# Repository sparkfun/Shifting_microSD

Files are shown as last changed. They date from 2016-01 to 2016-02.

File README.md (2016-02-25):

SparkFun Shifting µSD
===================================
SparkFun Shifting µSD

[*SparkFun Shifting µSD
 (DEV-13743)*](https://www.sparkfun.com/products/13743)

 Breakout board for the microSD socket that is not much bigger than your fingernail. Compatible with the SPI interface found on any SD card, this tiny form factor was created for cell phone storage and is perfect for your next data logging project!

Repository Contents
-------------------

* **/Hardware** &mdash; All Eagle design files (.brd, .sch)
* **/Firmware** &mdash; A trivial write only Arduino word processor.
* **/Production** &mdash; Test bed files and production panel files

Documentation
--------------
* **[Hookup Guide](https://learn.sparkfun.com/tutorials/microsd-breakout-with-level-shifter-hookup-guide)** &mdash; Basic hookup guide for the Shifting µSD.
* **[SparkFun Fritzing repo](https://github.com/sparkfun/Fritzing_Parts)** &mdash; Fritzing diagrams for SparkFun products.
* **[GitHub Repository](https://github.com/sparkfun/Shifting_microSD)** &mdash; Hardware design files and source code.

Product Versions
----------------
* [DEV-13743](https://www.sparkfun.com/products/13743) &mdash; µSD socket with integrated level shifter
* [BOB-00544](https://www.sparkfun.com/products/544) &mdash; µSD socket (3.3V)

Version History
---------------
* [V_10](https://www.sparkfun.com/products/13743) &mdash; Initial release

License Information
-------------------

This product is _**open source**_!

Please review the LICENSE.md file for license information.

If you have any questions or concerns on licensing, please contact TechSupport@SparkFun.com.

Distributed as-is; no warranty is given.

&mdash; Your friends at SparkFun.

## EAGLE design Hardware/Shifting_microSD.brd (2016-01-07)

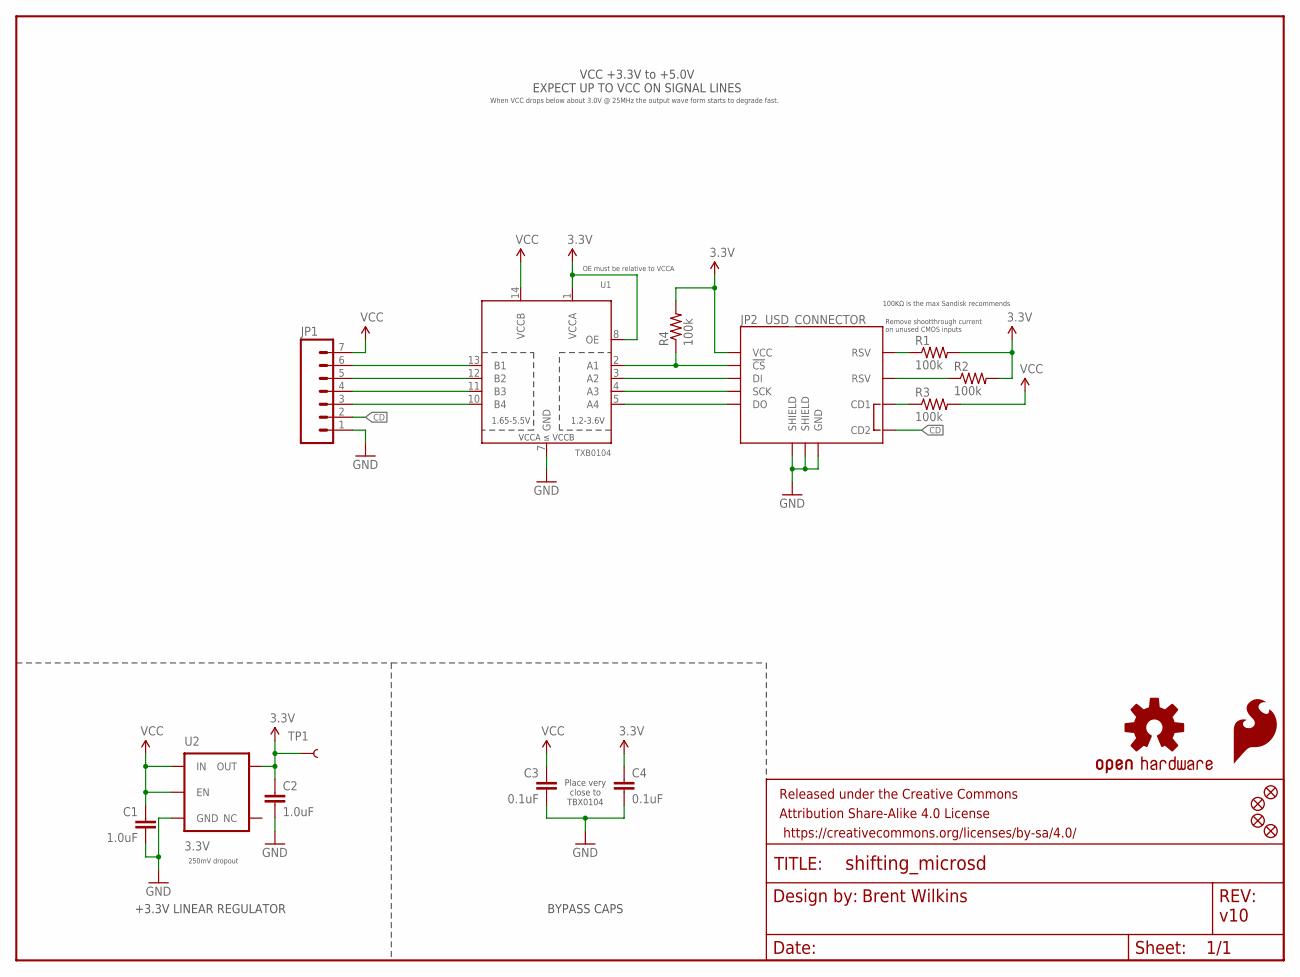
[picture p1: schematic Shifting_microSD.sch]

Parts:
C1, C2: 1.0uF; 0603-CAP
C3, C4: 0.1uF; 0603-CAP
FID1, FID2, FID3, FID4: FIDUCIAL1X2; FIDUCIAL-1X2
FRAME1: FRAME-LETTER; CREATIVE_COMMONS
JP1: M07; 1X07
JP2: USD_CONNECTOR; MICRO-SD-SOCKET-PP
LOGO1: SFE_LOGO_FLAME.2_INCH; SFE_LOGO_FLAME_.2
LOGO2: OSHW-LOGOS; OSHW-LOGO-S
R1, R2, R3, R4: 100k; 0603-RES
TP1: TEST-POINT3; PAD.03X.03
U1: TXB0104; SO14
U2: 3.3V; SOT23-5

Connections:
3V3: C2.1, C4.1, JP2.VCC, R1.2, R2.2, R4.2, TP1.P$1, U1.1 (VCCA), U1.8 (OE), U2.5 (OUT)
!CS_3V3: JP2.CS (!CS), R4.1, U1.2 (A1)
CD: JP1.2, JP2.CD2
CDSDSD: JP2.CD1, R3.1
DI: JP1.5, U1.12 (B2)
DI_3V3: JP2.DI, U1.3 (A2)
DO: JP1.3, U1.10 (B4)
DO_3V3: JP2.DO, U1.5 (A4)
GND: C1.2, C2.2, C3.2, C4.2, JP1.1, JP2.GND, JP2.GND1 (SHIELD), JP2.GND3 (SHIELD), U1.7 (GND), U2.2 (GND)
unnamed: JP1.6, U1.13 (B1)
unnamed: JP1.4, U1.11 (B3)
RSV@1: JP2.RSV1 (RSV), R1.1
RSV@2: JP2.RSV2 (RSV), R2.1
SCK_3V3: JP2.SCLK (SCK), U1.4 (A3)
VDD_IO: C1.1, C3.1, JP1.7, R3.2, U1.14 (VCCB), U2.1 (IN), U2.3 (EN)

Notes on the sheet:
Brent Wilkins
v10
VCC +3.3V to +5.0V EXPECT UP TO VCC ON SIGNAL LINES
Remove shootthrough current on unused CMOS inputs
Place very close to TBX0104
OE must be relative to VCCA
When VCC drops below about 3.0V @ 25MHz the output wave form starts to degrade fast.
+3.3V LINEAR REGULATOR
BYPASS CAPS
100KΩ is the max Sandisk recommends
250mV dropout

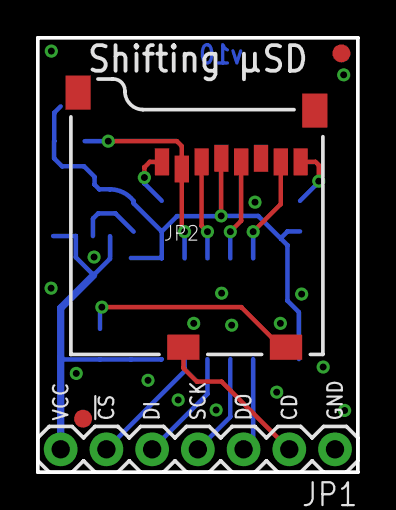
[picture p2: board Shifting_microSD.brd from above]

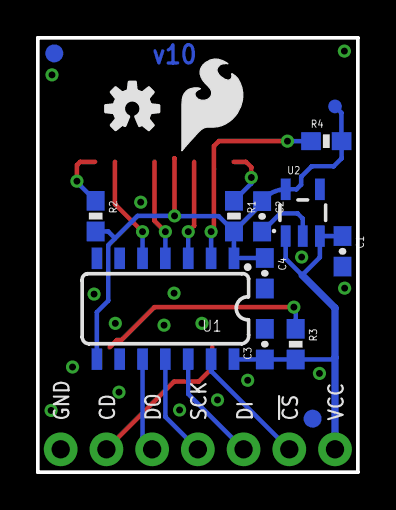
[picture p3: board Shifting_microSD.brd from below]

Board: 2 copper layers, 17.8 x 24.1 mm, 20 parts (15 on the bottom side), 15 nets.

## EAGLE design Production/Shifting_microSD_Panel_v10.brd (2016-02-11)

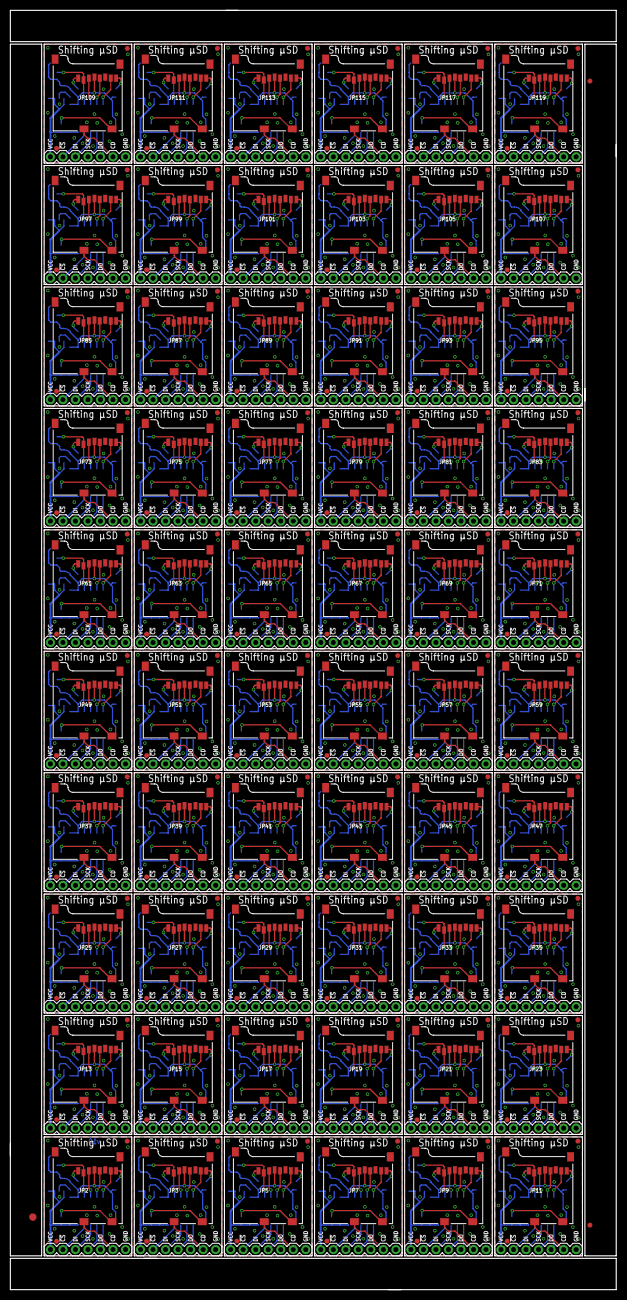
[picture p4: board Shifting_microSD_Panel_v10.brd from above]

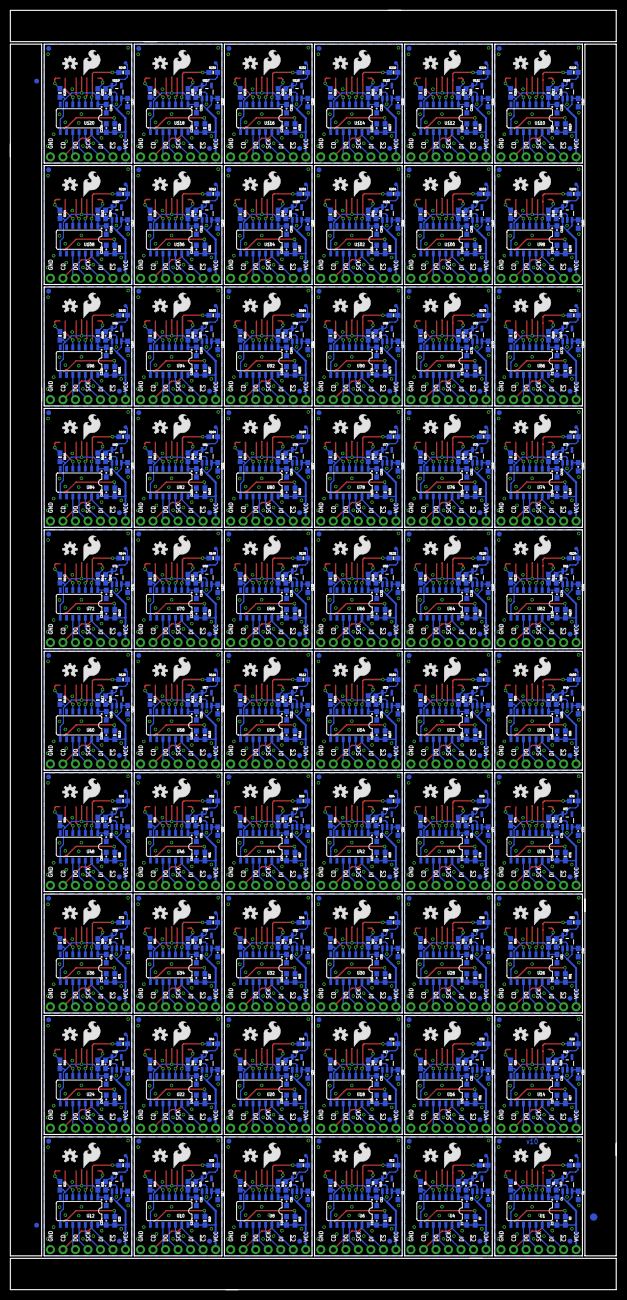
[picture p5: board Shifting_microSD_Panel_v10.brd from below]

Board: 2 copper layers, 122.9 x 259.6 mm, 1146 parts (903 on the bottom side), 900 nets.

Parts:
C1, C2, C5, C6, C9, C10, C13, C14, C17, C18, C21, C22, C25, C26, C29, C30, C33, C34, C37, C38, C41, C42, C45, C46, C49, C50, C53, C54, C57, C58, C61, C62, C65, C66, C69, C70, C73, C74, C77, C78, C81, C82, C85, C86, C89, C90, C93, C94, C97, C98, C101, C102, C105, C106, C109, C110, C113, C114, C117, C118, C121, C122, C125, C126, C129, C130, C133, C134, C137, C138, C141, C142, C145, C146, C149, C150, C153, C154, C157, C158, C161, C162, C165, C166, C169, C170, C173, C174, C177, C178, C181, C182, C185, C186, C189, C190, C193, C194, C197, C198, C201, C202, C205, C206, C209, C210, C213, C214, C217, C218, C221, C222, C225, C226, C229, C230, C233, C234, C237, C238: 1.0uF; 0603-CAP
C3, C4, C7, C8, C11, C12, C15, C16, C19, C20, C23, C24, C27, C28, C31, C32, C35, C36, C39, C40, C43, C44, C47, C48, C51, C52, C55, C56, C59, C60, C63, C64, C67, C68, C71, C72, C75, C76, C79, C80, C83, C84, C87, C88, C91, C92, C95, C96, C99, C100, C103, C104, C107, C108, C111, C112, C115, C116, C119, C120, C123, C124, C127, C128, C131, C132, C135, C136, C139, C140, C143, C144, C147, C148, C151, C152, C155, C156, C159, C160, C163, C164, C167, C168, C171, C172, C175, C176, C179, C180, C183, C184, C187, C188, C191, C192, C195, C196, C199, C200, C203, C204, C207, C208, C211, C212, C215, C216, C219, C220, C223, C224, C227, C228, C231, C232, C235, C236, C239, C240: 0.1uF; 0603-CAP
E$1, E$4, E$5, E$6: FIDUCIAL-1X2
E$2, E$3: FIDUCIAL-1.5X3
FID1, FID2, FID3, FID4, FID5, FID6, FID7, FID8, FID9, FID10, FID11, FID12, FID13, FID14, FID15, FID16, FID17, FID18, FID19, FID20, FID21, FID22, FID23, FID24, FID25, FID26, FID27, FID28, FID29, FID30, FID31, FID32, FID33, FID34, FID35, FID36, FID37, FID38, FID39, FID40, FID41, FID42, FID43, FID44, FID45, FID46, FID47, FID48, FID49, FID50, FID51, FID52, FID53, FID54, FID55, FID56, FID57, FID58, FID59, FID60, FID61, FID62, FID63, FID64, FID65, FID66, FID67, FID68, FID69, FID70, FID71, FID72, FID73, FID74, FID75, FID76, FID77, FID78, FID79, FID80, FID81, FID82, FID83, FID84, FID85, FID86, FID87, FID88, FID89, FID90, FID91, FID92, FID93, FID94, FID95, FID96, FID97, FID98, FID99, FID100, FID101, FID102, FID103, FID104, FID105, FID106, FID107, FID108, FID109, FID110, FID111, FID112, FID113, FID114, FID115, FID116, FID117, FID118, FID119, FID120, FID121, FID122, FID123, FID124, FID125, FID126, FID127, FID128, FID129, FID130, FID131, FID132, FID133, FID134, FID135, FID136, FID137, FID138, FID139, FID140, FID141, FID142, FID143, FID144, FID145, FID146, FID147, FID148, FID149, FID150, FID151, FID152, FID153, FID154, FID155, FID156, FID157, FID158, FID159, FID160, FID161, FID162, FID163, FID164, FID165, FID166, FID167, FID168, FID169, FID170, FID171, FID172, FID173, FID174, FID175, FID176, FID177, FID178, FID179, FID180, FID181, FID182, FID183, FID184, FID185, FID186, FID187, FID188, FID189, FID190, FID191, FID192, FID193, FID194, FID195, FID196, FID197, FID198, FID199, FID200, FID201, FID202, FID203, FID204, FID205, FID206, FID207, FID208, FID209, FID210, FID211, FID212, FID213, FID214, FID215, FID216, FID217, FID218, FID219, FID220, FID221, FID222, FID223, FID224, FID225, FID226, FID227, FID228, FID229, FID230, FID231, FID232, FID233, FID234, FID235, FID236, FID237, FID238, FID239, FID240: FIDUCIAL1X2; FIDUCIAL-1X2
JP1, JP4, JP6, JP8, JP10, JP12, JP14, JP16, JP18, JP20, JP22, JP24, JP26, JP28, JP30, JP32, JP34, JP36, JP38, JP40, JP42, JP44, JP46, JP48, JP50, JP52, JP54, JP56, JP58, JP60, JP62, JP64, JP66, JP68, JP70, JP72, JP74, JP76, JP78, JP80, JP82, JP84, JP86, JP88, JP90, JP92, JP94, JP96, JP98, JP100, JP102, JP104, JP106, JP108, JP110, JP112, JP114, JP116, JP118, JP120: 1X07
JP2, JP3, JP5, JP7, JP9, JP11, JP13, JP15, JP17, JP19, JP21, JP23, JP25, JP27, JP29, JP31, JP33, JP35, JP37, JP39, JP41, JP43, JP45, JP47, JP49, JP51, JP53, JP55, JP57, JP59, JP61, JP63, JP65, JP67, JP69, JP71, JP73, JP75, JP77, JP79, JP81, JP83, JP85, JP87, JP89, JP91, JP93, JP95, JP97, JP99, JP101, JP103, JP105, JP107, JP109, JP111, JP113, JP115, JP117, JP119: USD_CONNECTOR; MICRO-SD-SOCKET-PP
LOGO1, LOGO3, LOGO5, LOGO7, LOGO9, LOGO11, LOGO13, LOGO15, LOGO17, LOGO19, LOGO21, LOGO23, LOGO25, LOGO27, LOGO29, LOGO31, LOGO33, LOGO35, LOGO37, LOGO39, LOGO41, LOGO43, LOGO45, LOGO47, LOGO49, LOGO51, LOGO53, LOGO55, LOGO57, LOGO59, LOGO61, LOGO63, LOGO65, LOGO67, LOGO69, LOGO71, LOGO73, LOGO75, LOGO77, LOGO79, LOGO81, LOGO83, LOGO85, LOGO87, LOGO89, LOGO91, LOGO93, LOGO95, LOGO97, LOGO99, LOGO101, LOGO103, LOGO105, LOGO107, LOGO109, LOGO111, LOGO113, LOGO115, LOGO117, LOGO119: SFE_LOGO_FLAME.2_INCH; SFE_LOGO_FLAME_.2
LOGO2, LOGO4, LOGO6, LOGO8, LOGO10, LOGO12, LOGO14, LOGO16, LOGO18, LOGO20, LOGO22, LOGO24, LOGO26, LOGO28, LOGO30, LOGO32, LOGO34, LOGO36, LOGO38, LOGO40, LOGO42, LOGO44, LOGO46, LOGO48, LOGO50, LOGO52, LOGO54, LOGO56, LOGO58, LOGO60, LOGO62, LOGO64, LOGO66, LOGO68, LOGO70, LOGO72, LOGO74, LOGO76, LOGO78, LOGO80, LOGO82, LOGO84, LOGO86, LOGO88, LOGO90, LOGO92, LOGO94, LOGO96, LOGO98, LOGO100, LOGO102, LOGO104, LOGO106, LOGO108, LOGO110, LOGO112, LOGO114, LOGO116, LOGO118, LOGO120: OSHW-LOGOS; OSHW-LOGO-S
R1, R2, R3, R4, R5, R6, R7, R8, R9, R10, R11, R12, R13, R14, R15, R16, R17, R18, R19, R20, R21, R22, R23, R24, R25, R26, R27, R28, R29, R30, R31, R32, R33, R34, R35, R36, R37, R38, R39, R40, R41, R42, R43, R44, R45, R46, R47, R48, R49, R50, R51, R52, R53, R54, R55, R56, R57, R58, R59, R60, R61, R62, R63, R64, R65, R66, R67, R68, R69, R70, R71, R72, R73, R74, R75, R76, R77, R78, R79, R80, R81, R82, R83, R84, R85, R86, R87, R88, R89, R90, R91, R92, R93, R94, R95, R96, R97, R98, R99, R100, R101, R102, R103, R104, R105, R106, R107, R108, R109, R110, R111, R112, R113, R114, R115, R116, R117, R118, R119, R120, R121, R122, R123, R124, R125, R126, R127, R128, R129, R130, R131, R132, R133, R134, R135, R136, R137, R138, R139, R140, R141, R142, R143, R144, R145, R146, R147, R148, R149, R150, R151, R152, R153, R154, R155, R156, R157, R158, R159, R160, R161, R162, R163, R164, R165, R166, R167, R168, R169, R170, R171, R172, R173, R174, R175, R176, R177, R178, R179, R180, R181, R182, R183, R184, R185, R186, R187, R188, R189, R190, R191, R192, R193, R194, R195, R196, R197, R198, R199, R200, R201, R202, R203, R204, R205, R206, R207, R208, R209, R210, R211, R212, R213, R214, R215, R216, R217, R218, R219, R220, R221, R222, R223, R224, R225, R226, R227, R228, R229, R230, R231, R232, R233, R234, R235, R236, R237, R238, R239, R240: 100k; 0603-RES
TP1, TP2, TP3, TP4, TP5, TP6, TP7, TP8, TP9, TP10, TP11, TP12, TP13, TP14, TP15, TP16, TP17, TP18, TP19, TP20, TP21, TP22, TP23, TP24, TP25, TP26, TP27, TP28, TP29, TP30, TP31, TP32, TP33, TP34, TP35, TP36, TP37, TP38, TP39, TP40, TP41, TP42, TP43, TP44, TP45, TP46, TP47, TP48, TP49, TP50, TP51, TP52, TP53, TP54, TP55, TP56, TP57, TP58, TP59, TP60: PAD.03X.03
U1, U4, U6, U8, U10, U12, U14, U16, U18, U20, U22, U24, U26, U28, U30, U32, U34, U36, U38, U40, U42, U44, U46, U48, U50, U52, U54, U56, U58, U60, U62, U64, U66, U68, U70, U72, U74, U76, U78, U80, U82, U84, U86, U88, U90, U92, U94, U96, U98, U100, U102, U104, U106, U108, U110, U112, U114, U116, U118, U120: TXB0104; SO14
U2, U3, U5, U7, U9, U11, U13, U15, U17, U19, U21, U23, U25, U27, U29, U31, U33, U35, U37, U39, U41, U43, U45, U47, U49, U51, U53, U55, U57, U59, U61, U63, U65, U67, U69, U71, U73, U75, U77, U79, U81, U83, U85, U87, U89, U91, U93, U95, U97, U99, U101, U103, U105, U107, U109, U111, U113, U115, U117, U119: 3.3V; SOT23-5

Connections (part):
3V1: C6.1, C8.1, JP3.VCC, R5.2, R6.2, R8.2, TP2.P$1, U3.5, U4.1, U4.8
3V2: C10.1, C12.1, JP5.VCC, R9.2, R10.2, R12.2, TP3.P$1, U5.5, U6.1, U6.8
3V3: C2.1, C4.1, JP2.VCC, R1.2, R2.2, R4.2, TP1.P$1, U1.1, U1.8, U2.5
3V4: C14.1, C16.1, JP7.VCC, R13.2, R14.2, R16.2, TP4.P$1, U7.5, U8.1, U8.8
3V5: C18.1, C20.1, JP9.VCC, R17.2, R18.2, R20.2, TP5.P$1, U9.5, U10.1, U10.8
3V6: C22.1, C24.1, JP11.VCC, R21.2, R22.2, R24.2, TP6.P$1, U11.5, U12.1, U12.8
3V7: C26.1, C28.1, JP13.VCC, R25.2, R26.2, R28.2, TP7.P$1, U13.5, U14.1, U14.8
3V8: C30.1, C32.1, JP15.VCC, R29.2, R30.2, R32.2, TP8.P$1, U15.5, U16.1, U16.8
3V9: C34.1, C36.1, JP17.VCC, R33.2, R34.2, R36.2, TP9.P$1, U17.5, U18.1, U18.8
3V10: C38.1, C40.1, JP19.VCC, R37.2, R38.2, R40.2, TP10.P$1, U19.5, U20.1, U20.8
3V11: C42.1, C44.1, JP21.VCC, R41.2, R42.2, R44.2, TP11.P$1, U21.5, U22.1, U22.8
3V12: C46.1, C48.1, JP23.VCC, R45.2, R46.2, R48.2, TP12.P$1, U23.5, U24.1, U24.8
3V13: C50.1, C52.1, JP25.VCC, R49.2, R50.2, R52.2, TP13.P$1, U25.5, U26.1, U26.8
3V14: C54.1, C56.1, JP27.VCC, R53.2, R54.2, R56.2, TP14.P$1, U27.5, U28.1, U28.8
3V15: C58.1, C60.1, JP29.VCC, R57.2, R58.2, R60.2, TP15.P$1, U29.5, U30.1, U30.8
3V16: C62.1, C64.1, JP31.VCC, R61.2, R62.2, R64.2, TP16.P$1, U31.5, U32.1, U32.8
3V17: C66.1, C68.1, JP33.VCC, R65.2, R66.2, R68.2, TP17.P$1, U33.5, U34.1, U34.8
3V18: C70.1, C72.1, JP35.VCC, R69.2, R70.2, R72.2, TP18.P$1, U35.5, U36.1, U36.8
3V19: C74.1, C76.1, JP37.VCC, R73.2, R74.2, R76.2, TP19.P$1, U37.5, U38.1, U38.8
3V20: C78.1, C80.1, JP39.VCC, R77.2, R78.2, R80.2, TP20.P$1, U39.5, U40.1, U40.8
3V21: C82.1, C84.1, JP41.VCC, R81.2, R82.2, R84.2, TP21.P$1, U41.5, U42.1, U42.8
3V22: C86.1, C88.1, JP43.VCC, R85.2, R86.2, R88.2, TP22.P$1, U43.5, U44.1, U44.8
3V23: C90.1, C92.1, JP45.VCC, R89.2, R90.2, R92.2, TP23.P$1, U45.5, U46.1, U46.8
3V24: C94.1, C96.1, JP47.VCC, R93.2, R94.2, R96.2, TP24.P$1, U47.5, U48.1, U48.8
3V25: C98.1, C100.1, JP49.VCC, R97.2, R98.2, R100.2, TP25.P$1, U49.5, U50.1, U50.8
3V26: C102.1, C104.1, JP51.VCC, R101.2, R102.2, R104.2, TP26.P$1, U51.5, U52.1, U52.8
3V27: C106.1, C108.1, JP53.VCC, R105.2, R106.2, R108.2, TP27.P$1, U53.5, U54.1, U54.8
3V28: C110.1, C112.1, JP55.VCC, R109.2, R110.2, R112.2, TP28.P$1, U55.5, U56.1, U56.8
3V29: C114.1, C116.1, JP57.VCC, R113.2, R114.2, R116.2, TP29.P$1, U57.5, U58.1, U58.8
3V30: C118.1, C120.1, JP59.VCC, R117.2, R118.2, R120.2, TP30.P$1, U59.5, U60.1, U60.8
3V31: C122.1, C124.1, JP61.VCC, R121.2, R122.2, R124.2, TP31.P$1, U61.5, U62.1, U62.8
3V32: C126.1, C128.1, JP63.VCC, R125.2, R126.2, R128.2, TP32.P$1, U63.5, U64.1, U64.8
3V33: C130.1, C132.1, JP65.VCC, R129.2, R130.2, R132.2, TP33.P$1, U65.5, U66.1, U66.8
3V34: C134.1, C136.1, JP67.VCC, R133.2, R134.2, R136.2, TP34.P$1, U67.5, U68.1, U68.8
3V35: C138.1, C140.1, JP69.VCC, R137.2, R138.2, R140.2, TP35.P$1, U69.5, U70.1, U70.8
3V36: C142.1, C144.1, JP71.VCC, R141.2, R142.2, R144.2, TP36.P$1, U71.5, U72.1, U72.8
3V37: C146.1, C148.1, JP73.VCC, R145.2, R146.2, R148.2, TP37.P$1, U73.5, U74.1, U74.8
3V38: C150.1, C152.1, JP75.VCC, R149.2, R150.2, R152.2, TP38.P$1, U75.5, U76.1, U76.8
3V39: C154.1, C156.1, JP77.VCC, R153.2, R154.2, R156.2, TP39.P$1, U77.5, U78.1, U78.8
3V40: C158.1, C160.1, JP79.VCC, R157.2, R158.2, R160.2, TP40.P$1, U79.5, U80.1, U80.8
3V41: C162.1, C164.1, JP81.VCC, R161.2, R162.2, R164.2, TP41.P$1, U81.5, U82.1, U82.8
3V42: C166.1, C168.1, JP83.VCC, R165.2, R166.2, R168.2, TP42.P$1, U83.5, U84.1, U84.8
3V43: C170.1, C172.1, JP85.VCC, R169.2, R170.2, R172.2, TP43.P$1, U85.5, U86.1, U86.8
3V44: C174.1, C176.1, JP87.VCC, R173.2, R174.2, R176.2, TP44.P$1, U87.5, U88.1, U88.8
3V45: C178.1, C180.1, JP89.VCC, R177.2, R178.2, R180.2, TP45.P$1, U89.5, U90.1, U90.8
3V46: C182.1, C184.1, JP91.VCC, R181.2, R182.2, R184.2, TP46.P$1, U91.5, U92.1, U92.8
3V47: C186.1, C188.1, JP93.VCC, R185.2, R186.2, R188.2, TP47.P$1, U93.5, U94.1, U94.8
3V48: C190.1, C192.1, JP95.VCC, R189.2, R190.2, R192.2, TP48.P$1, U95.5, U96.1, U96.8
3V49: C194.1, C196.1, JP97.VCC, R193.2, R194.2, R196.2, TP49.P$1, U97.5, U98.1, U98.8
3V50: C198.1, C200.1, JP99.VCC, R197.2, R198.2, R200.2, TP50.P$1, U99.5, U100.1, U100.8
3V51: C202.1, C204.1, JP101.VCC, R201.2, R202.2, R204.2, TP51.P$1, U101.5, U102.1, U102.8
3V52: C206.1, C208.1, JP103.VCC, R205.2, R206.2, R208.2, TP52.P$1, U103.5, U104.1, U104.8
3V53: C210.1, C212.1, JP105.VCC, R209.2, R210.2, R212.2, TP53.P$1, U105.5, U106.1, U106.8
3V54: C214.1, C216.1, JP107.VCC, R213.2, R214.2, R216.2, TP54.P$1, U107.5, U108.1, U108.8
3V55: C218.1, C220.1, JP109.VCC, R217.2, R218.2, R220.2, TP55.P$1, U109.5, U110.1, U110.8
3V56: C222.1, C224.1, JP111.VCC, R221.2, R222.2, R224.2, TP56.P$1, U111.5, U112.1, U112.8
3V57: C226.1, C228.1, JP113.VCC, R225.2, R226.2, R228.2, TP57.P$1, U113.5, U114.1, U114.8
3V58: C230.1, C232.1, JP115.VCC, R229.2, R230.2, R232.2, TP58.P$1, U115.5, U116.1, U116.8
3V59: C234.1, C236.1, JP117.VCC, R233.2, R234.2, R236.2, TP59.P$1, U117.5, U118.1, U118.8
3V60: C238.1, C240.1, JP119.VCC, R237.2, R238.2, R240.2, TP60.P$1, U119.5, U120.1, U120.8
!CS_3V1: JP3.CS, R8.1, U4.2
!CS_3V2: JP5.CS, R12.1, U6.2
!CS_3V3: JP2.CS, R4.1, U1.2
!CS_3V4: JP7.CS, R16.1, U8.2
!CS_3V5: JP9.CS, R20.1, U10.2
!CS_3V6: JP11.CS, R24.1, U12.2
!CS_3V7: JP13.CS, R28.1, U14.2
!CS_3V8: JP15.CS, R32.1, U16.2
!CS_3V9: JP17.CS, R36.1, U18.2
!CS_3V10: JP19.CS, R40.1, U20.2
!CS_3V11: JP21.CS, R44.1, U22.2
!CS_3V12: JP23.CS, R48.1, U24.2
!CS_3V13: JP25.CS, R52.1, U26.2
!CS_3V14: JP27.CS, R56.1, U28.2
!CS_3V15: JP29.CS, R60.1, U30.2
!CS_3V16: JP31.CS, R64.1, U32.2
!CS_3V17: JP33.CS, R68.1, U34.2
!CS_3V18: JP35.CS, R72.1, U36.2
!CS_3V19: JP37.CS, R76.1, U38.2
!CS_3V20: JP39.CS, R80.1, U40.2
!CS_3V21: JP41.CS, R84.1, U42.2
!CS_3V22: JP43.CS, R88.1, U44.2
!CS_3V23: JP45.CS, R92.1, U46.2
!CS_3V24: JP47.CS, R96.1, U48.2
!CS_3V25: JP49.CS, R100.1, U50.2
!CS_3V26: JP51.CS, R104.1, U52.2
!CS_3V27: JP53.CS, R108.1, U54.2
!CS_3V28: JP55.CS, R112.1, U56.2
!CS_3V29: JP57.CS, R116.1, U58.2
!CS_3V30: JP59.CS, R120.1, U60.2
!CS_3V31: JP61.CS, R124.1, U62.2
!CS_3V32: JP63.CS, R128.1, U64.2
!CS_3V33: JP65.CS, R132.1, U66.2
!CS_3V34: JP67.CS, R136.1, U68.2
!CS_3V35: JP69.CS, R140.1, U70.2
!CS_3V36: JP71.CS, R144.1, U72.2
!CS_3V37: JP73.CS, R148.1, U74.2
!CS_3V38: JP75.CS, R152.1, U76.2
!CS_3V39: JP77.CS, R156.1, U78.2
!CS_3V40: JP79.CS, R160.1, U80.2
!CS_3V41: JP81.CS, R164.1, U82.2
!CS_3V42: JP83.CS, R168.1, U84.2
!CS_3V43: JP85.CS, R172.1, U86.2
!CS_3V44: JP87.CS, R176.1, U88.2
!CS_3V45: JP89.CS, R180.1, U90.2
!CS_3V46: JP91.CS, R184.1, U92.2
!CS_3V47: JP93.CS, R188.1, U94.2
!CS_3V48: JP95.CS, R192.1, U96.2
!CS_3V49: JP97.CS, R196.1, U98.2
!CS_3V50: JP99.CS, R200.1, U100.2
!CS_3V51: JP101.CS, R204.1, U102.2
!CS_3V52: JP103.CS, R208.1, U104.2
!CS_3V53: JP105.CS, R212.1, U106.2
!CS_3V54: JP107.CS, R216.1, U108.2
!CS_3V55: JP109.CS, R220.1, U110.2
!CS_3V56: JP111.CS, R224.1, U112.2
!CS_3V57: JP113.CS, R228.1, U114.2
!CS_3V58: JP115.CS, R232.1, U116.2
!CS_3V59: JP117.CS, R236.1, U118.2
!CS_3V60: JP119.CS, R240.1, U120.2
CD: JP1.2, JP2.CD2
CD1: JP3.CD2, JP4.2
CD2: JP5.CD2, JP6.2
CD3: JP7.CD2, JP8.2
CD4: JP9.CD2, JP10.2
CD5: JP11.CD2, JP12.2
CD6: JP13.CD2, JP14.2
CD7: JP15.CD2, JP16.2
CD8: JP17.CD2, JP18.2
CD9: JP19.CD2, JP20.2
CD10: JP21.CD2, JP22.2
CD11: JP23.CD2, JP24.2
CD12: JP25.CD2, JP26.2
CD13: JP27.CD2, JP28.2
CD14: JP29.CD2, JP30.2
CD15: JP31.CD2, JP32.2
CD16: JP33.CD2, JP34.2
CD17: JP35.CD2, JP36.2
CD18: JP37.CD2, JP38.2
CD19: JP39.CD2, JP40.2
CD20: JP41.CD2, JP42.2
CD21: JP43.CD2, JP44.2
CD22: JP45.CD2, JP46.2
CD23: JP47.CD2, JP48.2
CD24: JP49.CD2, JP50.2
CD25: JP51.CD2, JP52.2
CD26: JP53.CD2, JP54.2
CD27: JP55.CD2, JP56.2
CD28: JP57.CD2, JP58.2
CD29: JP59.CD2, JP60.2
CD30: JP61.CD2, JP62.2
CD31: JP63.CD2, JP64.2
CD32: JP65.CD2, JP66.2
CD33: JP67.CD2, JP68.2
CD34: JP69.CD2, JP70.2
CD35: JP71.CD2, JP72.2
CD36: JP73.CD2, JP74.2
CD37: JP75.CD2, JP76.2
CD38: JP77.CD2, JP78.2
CD39: JP79.CD2, JP80.2
CD40: JP81.CD2, JP82.2
CD41: JP83.CD2, JP84.2
CD42: JP85.CD2, JP86.2
CD43: JP87.CD2, JP88.2
CD44: JP89.CD2, JP90.2
CD45: JP91.CD2, JP92.2
CD46: JP93.CD2, JP94.2
CD47: JP95.CD2, JP96.2
CD48: JP97.CD2, JP98.2
CD49: JP99.CD2, JP100.2
CD50: JP101.CD2, JP102.2
CD51: JP103.CD2, JP104.2
CD52: JP105.CD2, JP106.2
CD53: JP107.CD2, JP108.2
CD54: JP109.CD2, JP110.2
CD55: JP111.CD2, JP112.2
CD56: JP113.CD2, JP114.2
CD57: JP115.CD2, JP116.2
CD58: JP117.CD2, JP118.2
CD59: JP119.CD2, JP120.2
CDSDSD: JP2.CD1, R3.1
CDSDSD1: JP3.CD1, R7.1
CDSDSD2: JP5.CD1, R11.1
CDSDSD3: JP7.CD1, R15.1
CDSDSD4: JP9.CD1, R19.1
CDSDSD5: JP11.CD1, R23.1
CDSDSD6: JP13.CD1, R27.1
CDSDSD7: JP15.CD1, R31.1
CDSDSD8: JP17.CD1, R35.1
CDSDSD9: JP19.CD1, R39.1
CDSDSD10: JP21.CD1, R43.1
CDSDSD11: JP23.CD1, R47.1
CDSDSD12: JP25.CD1, R51.1
CDSDSD13: JP27.CD1, R55.1
CDSDSD14: JP29.CD1, R59.1
CDSDSD15: JP31.CD1, R63.1
CDSDSD16: JP33.CD1, R67.1
CDSDSD17: JP35.CD1, R71.1
CDSDSD18: JP37.CD1, R75.1
CDSDSD19: JP39.CD1, R79.1
CDSDSD20: JP41.CD1, R83.1
CDSDSD21: JP43.CD1, R87.1
CDSDSD22: JP45.CD1, R91.1
CDSDSD23: JP47.CD1, R95.1
CDSDSD24: JP49.CD1, R99.1
CDSDSD25: JP51.CD1, R103.1
CDSDSD26: JP53.CD1, R107.1
CDSDSD27: JP55.CD1, R111.1
CDSDSD28: JP57.CD1, R115.1
CDSDSD29: JP59.CD1, R119.1
CDSDSD30: JP61.CD1, R123.1
CDSDSD31: JP63.CD1, R127.1
CDSDSD32: JP65.CD1, R131.1
CDSDSD33: JP67.CD1, R135.1
CDSDSD34: JP69.CD1, R139.1
CDSDSD35: JP71.CD1, R143.1
CDSDSD36: JP73.CD1, R147.1
CDSDSD37: JP75.CD1, R151.1
CDSDSD38: JP77.CD1, R155.1
CDSDSD39: JP79.CD1, R159.1
CDSDSD40: JP81.CD1, R163.1
CDSDSD41: JP83.CD1, R167.1
CDSDSD42: JP85.CD1, R171.1
CDSDSD43: JP87.CD1, R175.1
CDSDSD44: JP89.CD1, R179.1
CDSDSD45: JP91.CD1, R183.1
CDSDSD46: JP93.CD1, R187.1
CDSDSD47: JP95.CD1, R191.1
CDSDSD48: JP97.CD1, R195.1
CDSDSD49: JP99.CD1, R199.1
CDSDSD50: JP101.CD1, R203.1
CDSDSD51: JP103.CD1, R207.1
CDSDSD52: JP105.CD1, R211.1
CDSDSD53: JP107.CD1, R215.1
CDSDSD54: JP109.CD1, R219.1
CDSDSD55: JP111.CD1, R223.1
CDSDSD56: JP113.CD1, R227.1
CDSDSD57: JP115.CD1, R231.1
CDSDSD58: JP117.CD1, R235.1
CDSDSD59: JP119.CD1, R239.1
DI: JP1.5, U1.12
DI1: JP4.5, U4.12
DI2: JP6.5, U6.12
DI3: JP8.5, U8.12
DI4: JP10.5, U10.12
DI5: JP12.5, U12.12
DI6: JP14.5, U14.12
DI7: JP16.5, U16.12
DI8: JP18.5, U18.12
DI9: JP20.5, U20.12
DI10: JP22.5, U22.12
DI11: JP24.5, U24.12
DI12: JP26.5, U26.12
DI13: JP28.5, U28.12
DI14: JP30.5, U30.12
DI15: JP32.5, U32.12
DI16: JP34.5, U34.12
DI17: JP36.5, U36.12
DI18: JP38.5, U38.12
DI19: JP40.5, U40.12
DI20: JP42.5, U42.12
DI21: JP44.5, U44.12
DI22: JP46.5, U46.12
DI23: JP48.5, U48.12
DI24: JP50.5, U50.12
DI25: JP52.5, U52.12
DI26: JP54.5, U54.12
DI27: JP56.5, U56.12
DI28: JP58.5, U58.12
DI29: JP60.5, U60.12
DI30: JP62.5, U62.12
DI31: JP64.5, U64.12
DI32: JP66.5, U66.12
DI33: JP68.5, U68.12
DI34: JP70.5, U70.12
DI35: JP72.5, U72.12
DI36: JP74.5, U74.12
DI37: JP76.5, U76.12
DI38: JP78.5, U78.12
DI39: JP80.5, U80.12
DI40: JP82.5, U82.12
DI41: JP84.5, U84.12
DI42: JP86.5, U86.12
DI43: JP88.5, U88.12
DI44: JP90.5, U90.12
DI45: JP92.5, U92.12
DI46: JP94.5, U94.12
DI47: JP96.5, U96.12
DI48: JP98.5, U98.12
DI49: JP100.5, U100.12
DI50: JP102.5, U102.12
DI51: JP104.5, U104.12
DI52: JP106.5, U106.12
DI53: JP108.5, U108.12
DI54: JP110.5, U110.12
DI55: JP112.5, U112.12
DI56: JP114.5, U114.12
DI57: JP116.5, U116.12
DI58: JP118.5, U118.12
DI59: JP120.5, U120.12
DI_3V1: JP3.DI, U4.3
DI_3V2: JP5.DI, U6.3
DI_3V3: JP2.DI, U1.3
DI_3V4: JP7.DI, U8.3
DI_3V5: JP9.DI, U10.3
DI_3V6: JP11.DI, U12.3
DI_3V7: JP13.DI, U14.3
DI_3V8: JP15.DI, U16.3
DI_3V9: JP17.DI, U18.3
DI_3V10: JP19.DI, U20.3
DI_3V11: JP21.DI, U22.3
DI_3V12: JP23.DI, U24.3
DI_3V13: JP25.DI, U26.3
DI_3V14: JP27.DI, U28.3
DI_3V15: JP29.DI, U30.3
DI_3V16: JP31.DI, U32.3
DI_3V17: JP33.DI, U34.3
DI_3V18: JP35.DI, U36.3
DI_3V19: JP37.DI, U38.3
DI_3V20: JP39.DI, U40.3
DI_3V21: JP41.DI, U42.3
DI_3V22: JP43.DI, U44.3
DI_3V23: JP45.DI, U46.3
DI_3V24: JP47.DI, U48.3
DI_3V25: JP49.DI, U50.3
DI_3V26: JP51.DI, U52.3
DI_3V27: JP53.DI, U54.3
DI_3V28: JP55.DI, U56.3
DI_3V29: JP57.DI, U58.3
DI_3V30: JP59.DI, U60.3
DI_3V31: JP61.DI, U62.3
DI_3V32: JP63.DI, U64.3
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

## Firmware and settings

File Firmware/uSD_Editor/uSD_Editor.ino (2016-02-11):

/*
 * A simple file logger that allows the user to write to a file on the µSD card
 * using the Arduino IDE Serial Monitor (57600 baud). Entered text is written
 * to the µSD card every 20 characters, but to make sure everything is written
 * append 'EOF' to your writing. Doing so writes everything remaining in the
 * buffer to the file and reads back the contents of the file.
 */

#include <SPI.h>
#include <SD.h>

File fd;
const uint8_t BUFFER_SIZE = 20;
char fileName[] = "demoFile.txt"; // SD library only supports up to 8.3 names
char buff[BUFFER_SIZE+2] = "";  // Added two to allow a 2 char peek for EOF state
uint8_t index = 0;

const uint8_t chipSelect = 8;
const uint8_t cardDetect = 9;

enum states: uint8_t { NORMAL, E, EO };
uint8_t state = NORMAL;

bool alreadyBegan = false;  // SD.begin() misbehaves if not first call



////////////////////////////////////////////////////////////////////////////////
// Standard Arduino setup function
////////////////////////////////////////////////////////////////////////////////
void setup()
{
  Serial.begin(57600);
  while (!Serial);  // Wait for serial port to connect (ATmega32U4 type PCBAs)

  // Note: To satisfy the AVR SPI gods the SD library takes care of setting
  // SS_PIN as an output. We don't need to.
  pinMode(cardDetect, INPUT);

  initializeCard();
}



////////////////////////////////////////////////////////////////////////////////
// Arduino calls this function over and over again when running
////////////////////////////////////////////////////////////////////////////////
void loop()
{
  // Make sure the card is still present
  if (!digitalRead(cardDetect))
  {
    initializeCard();
  }

  if (Serial.available() > 0)
  {
    readByte();
    
    if (index == BUFFER_SIZE)
    {
      flushBuffer();  // Write full buffer to µSD card
    }
  }
}



////////////////////////////////////////////////////////////////////////////////
// Do everything from detecting card through opening the demo file
////////////////////////////////////////////////////////////////////////////////
void initializeCard(void)
{
  Serial.print(F("Initializing SD card..."));
  
  // Is there even a card?
  if (!digitalRead(cardDetect))
  {
    Serial.println(F("No card detected. Waiting for card."));
    while (!digitalRead(cardDetect));
    delay(250); // 'Debounce insertion'
  }
  
  // Card seems to exist.  begin() returns failure
  // even if it worked if it's not the first call.
  if (!SD.begin(chipSelect) && !alreadyBegan)  // begin uses half-speed...
  {
    Serial.println(F("Initialization failed!"));
    initializeCard(); // Possible infinite retry loop is as valid as anything
  }
  else
  {
    alreadyBegan = true;
  }
  Serial.println(F("Initialization done."));

  Serial.print(fileName);
  if (SD.exists(fileName))
  {
    Serial.println(F(" exists."));
  }
  else
  {
    Serial.println(F(" doesn't exist. Creating."));
  }
  
  Serial.print("Opening file: ");
  Serial.println(fileName);

  Serial.println(F("Enter text to be written to file. 'EOF' will terminate writing."));
}


////////////////////////////////////////////////////////////////////////////////
// This function is called after the EOF command is received. It writes the
// remaining unwritten data to the µSD card, and prints out the full contents
// of the log file.
////////////////////////////////////////////////////////////////////////////////
void eof(void)
{
  index -= 3; // Remove EOF from the end
  flushBuffer();
  
  // Re-open the file for reading:
  fd = SD.open(fileName);
  if (fd)
  {
    Serial.println("");
    Serial.print(fileName);
    Serial.println(":");

    while (fd.available())
    {
      Serial.write(fd.read());
    }
  }
  else
  {
    Serial.print("Error opening ");
    Serial.println(fileName);
  }
  fd.close();
}


////////////////////////////////////////////////////////////////////////////////
// Write the buffer to the log file. If we are possibly in the EOF state, verify
// that to make sure the command isn't written to the file.
////////////////////////////////////////////////////////////////////////////////
void flushBuffer(void)
{
  fd = SD.open(fileName, FILE_WRITE);
  if (fd) {
    switch (state)  // If a flush occurs in the 'E' or the 'EO' state, read more to detect EOF
    {
    case NORMAL:
      break;
    case E:
      readByte();
      readByte();
      break;
    case EO:
      readByte();
      break;
    }
    fd.write(buff, index);
    fd.flush();
    index = 0;
    fd.close();
  }
}



////////////////////////////////////////////////////////////////////////////////
// Reads a byte from the serial connection. This also maintains the state to
// capture the EOF command.
////////////////////////////////////////////////////////////////////////////////
void readByte(void)
{
  byte byteRead = Serial.read();
  Serial.write(byteRead); // Echo
  buff[index++] = byteRead;
  
  // Must be 'EOF' to not get confused with words such as 'takeoff' or 'writeoff'
  if (byteRead == 'E' && state == NORMAL)
  {
    state = E;
  }
  else if (byteRead == 'O' && state == E)
  {
    state = EO;
  }
  else if (byteRead == 'F' && state == EO)
  {
    eof();
    state = NORMAL;
  }
}

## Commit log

2015-10-08 Initial design finished
    [Shifting_microSD.brd, Shifting_microSD.sch]
2015-10-08 Added CS pull-up
    [Shifting_microSD.brd, Shifting_microSD.sch]
2015-10-12 Added more notes
    [Shifting_microSD.sch]
2015-10-12 Fixed copy paste error on bypass caps
    [Shifting_microSD.sch]
2015-10-13 Increased size of version font
    [Shifting_microSD.brd]
2015-11-04 Connected both 3.3V nets
    [Shifting_microSD.brd, Shifting_microSD.sch]
2015-11-23 Incremented to v10
    [Shifting_microSD.brd, Shifting_microSD.sch]
2015-11-24 Increased via sizes and shrunk PCB to exact width of header
    [Shifting_microSD.brd, Shifting_microSD.sch]
2015-11-24 warped a trace
    [Shifting_microSD.brd]
2015-11-25 Renamed a jack to JP and moved over a test point
    [Shifting_microSD.brd, Shifting_microSD.sch]
2016-01-07 updated version number for production
    [Shifting_microSD.brd, Shifting_microSD.sch]
2016-01-08 created panel v10
    [Shifting_microSD_Panel_v10.brd]
2016-02-01 added bottom side panel fiducials
    [Shifting_microSD_Panel_v10.brd]

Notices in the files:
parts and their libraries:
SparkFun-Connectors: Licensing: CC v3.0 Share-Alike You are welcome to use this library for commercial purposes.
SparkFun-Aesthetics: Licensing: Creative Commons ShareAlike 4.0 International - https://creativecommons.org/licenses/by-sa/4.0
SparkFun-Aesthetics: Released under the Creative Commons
